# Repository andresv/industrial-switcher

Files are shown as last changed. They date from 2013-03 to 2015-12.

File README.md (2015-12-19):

## industrial-switcher

This board is meant for switching various 24V loads, like coils and relays.

## Requirements

[PlatformIO](http://platformio.org) is used for building.

```
pip install -U pip setuptools
pip install -U platformio
platformio platforms install timsp430
```

## Build and upload
```
platformio run
platformio run --target upload
```

## License

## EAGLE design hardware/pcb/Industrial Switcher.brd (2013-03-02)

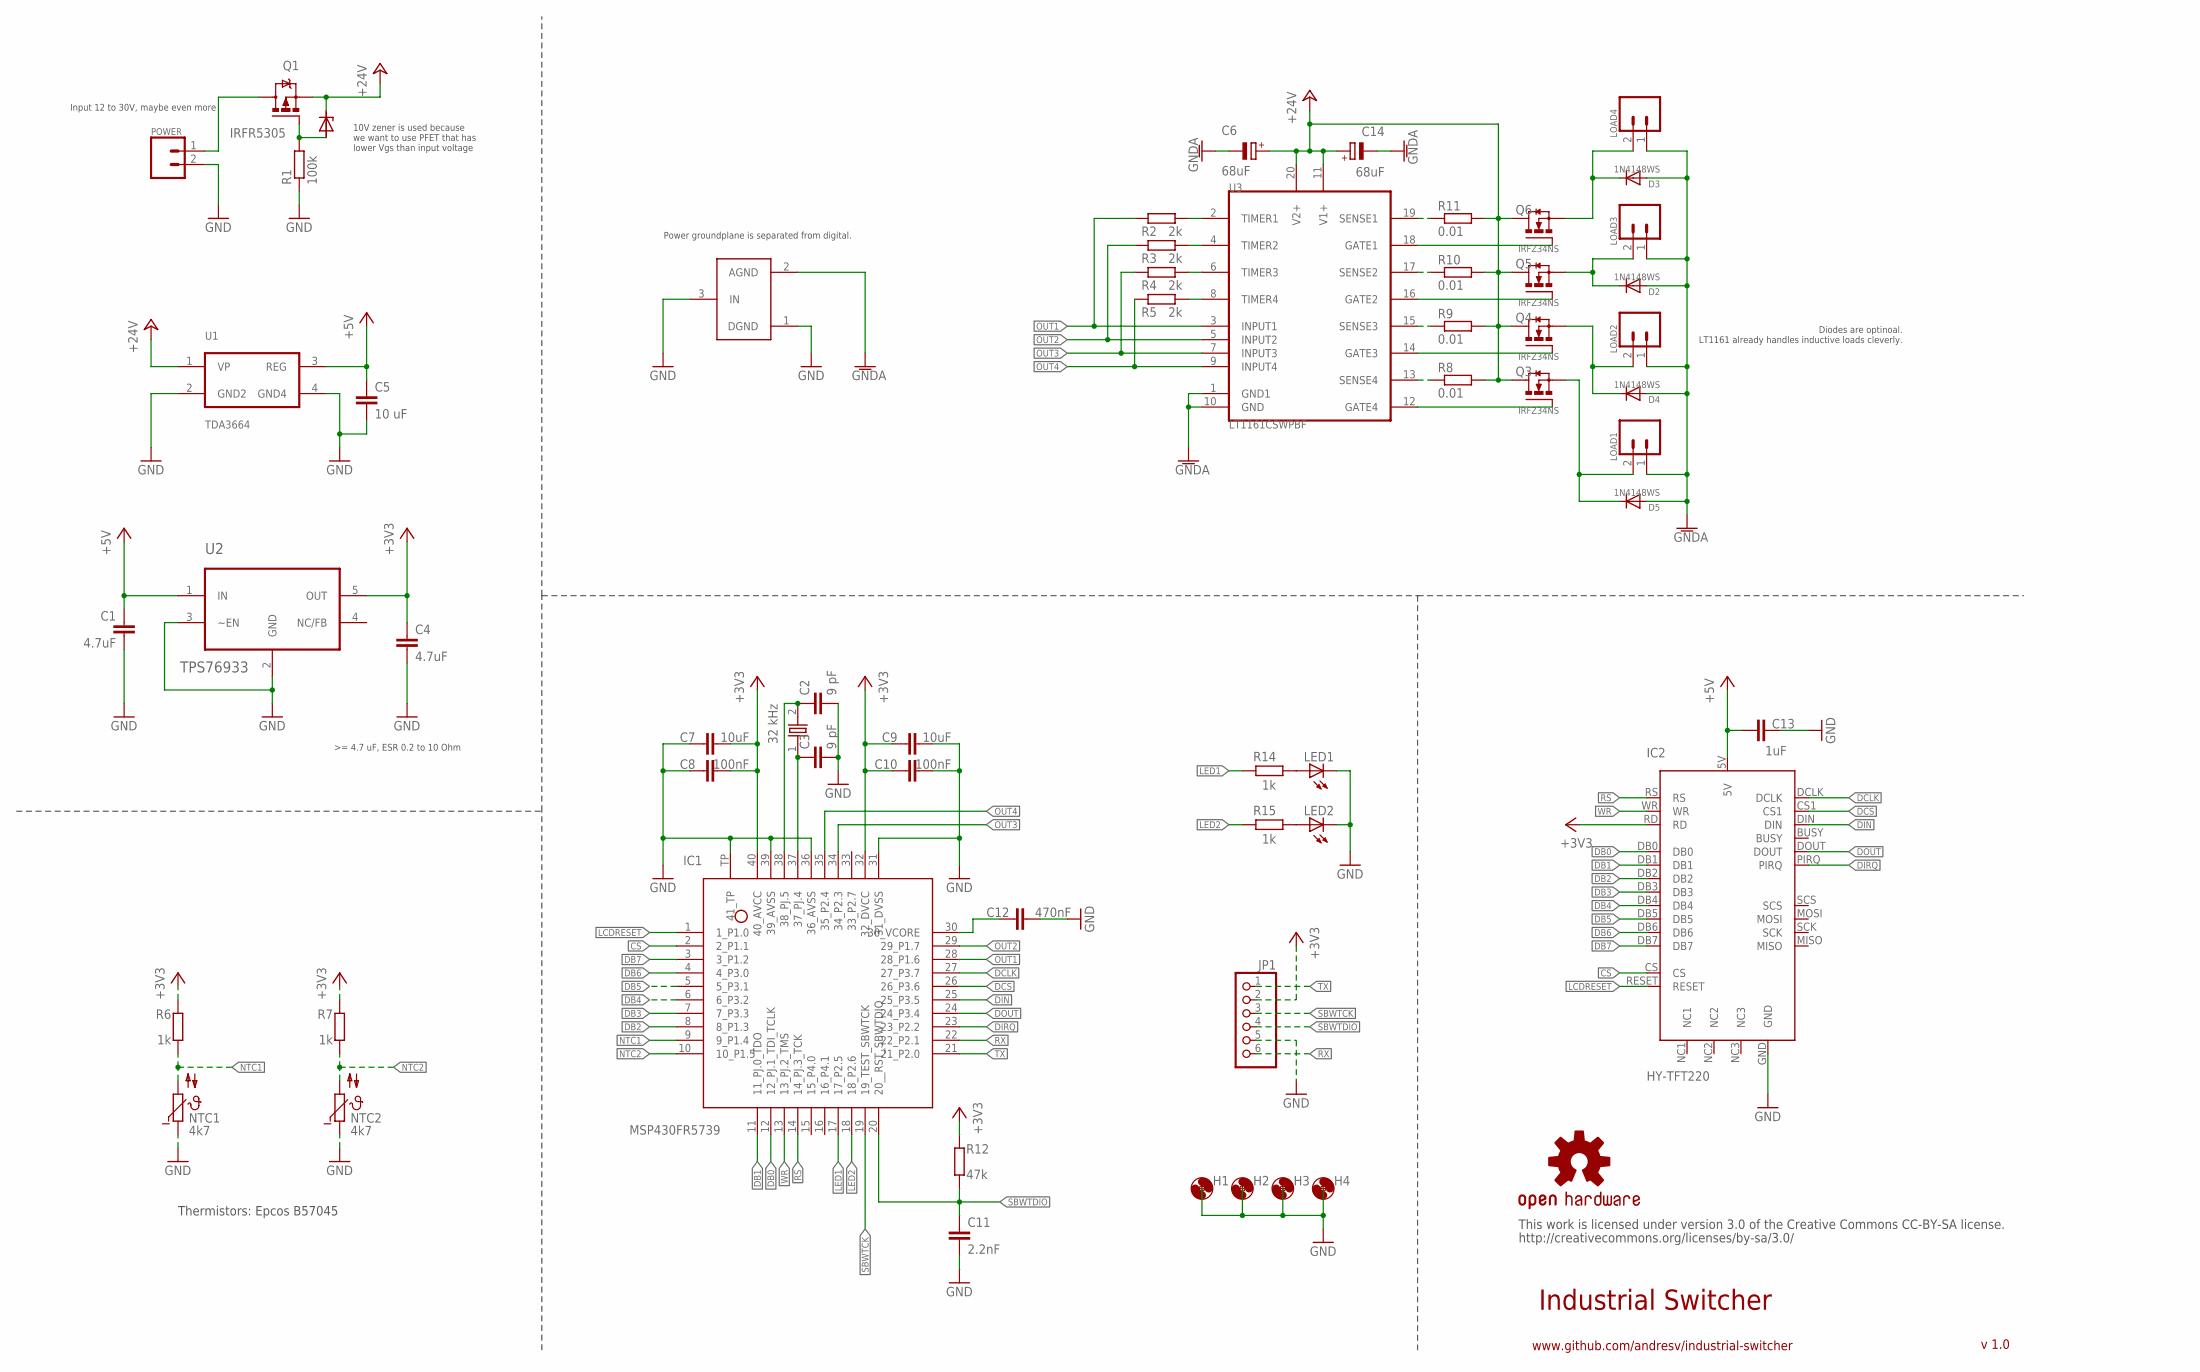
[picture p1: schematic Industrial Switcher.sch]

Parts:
C1: 4.7uF; C0805
C2, C3: 9 pF; C0402
C4: 4.7uF; C1206
C5: 10 uF; C1206
C6, C14: 68uF; PANASONIC_F
C7, C9: 10uF; C0603
C8, C10: 100nF; C0603
C11: 2.2nF; C0402
C12: 470nF; C0603
C13: 1uF; C0805
D1: 10V; SOD323-W
D2, D3, D4, D5: 1N4148WS; SOD323-W
H1, H2, H3, H4: MOUNT-HOLE3.0; 3,0
IC1: MSP430FR5739; RHA40
IC2: HY-TFT220; 2.2TFT
JP1: PINHD-1X6; 1X06
LED1, LED2: LEDCHIP-LED0603; CHIP-LED0603
LOAD1, LOAD2, LOAD3, LOAD4: M025MM; SCREWTERMINAL-5MM-2
LOGO2: OSHW-LOGOL; OSHW-LOGO-L
NTC1, NTC2: 4k7; N640
POWER: M025MM; SCREWTERMINAL-5MM-2
Q1: IRFR5305; D-PAK_TO252AA
Q2: 32 kHz; ABS07
Q3, Q4, Q5, Q6: IRFZ34NS; D2PACK
R1: 100k; R0603
R2, R3, R4, R5: 2k; R0603
R6, R7: 1k; R0603
R8, R9, R10, R11: 0.01; R0603
R12: 47k; R0402
R14, R15: 1k; R0402
U1: TDA3664; DRFRIEDPARTS/DOAAZ
U2: TPS76933; SOT95P280X145-5N
U3: LT1161CSWPBF; ANDRESV/B3JU7
U$1: GND_CONNECT

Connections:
+3V3: C4.1, C7.2, C8.2, C9.1, C10.1, IC1.32 (32_DVCC), IC1.40 (40_AVCC), IC2.RD, JP1.2, R6.2, R7.2, R12.2, U2.5 (OUT)
+5V: C1.1, C5.1, C13.2, IC2.5V, U1.3 (REG), U2.1 (IN)
+24V: C6.+, C14.+, D1.C, Q1.3 (S), Q3.2 (D), Q4.2 (D), Q5.2 (D), Q6.2 (D), R8.2, R9.2, R10.2, R11.2, U1.1 (VP), U3.11 (V1+), U3.20 (V2+)
CS: IC1.2 (2_P1.1), IC2.CS
DB0: IC1.12 (12_PJ.1_TDI_TCLK), IC2.DB0
DB1: IC1.11 (11_PJ.0_TDO), IC2.DB1
DB2: IC1.8 (8_P1.3), IC2.DB2
DB3: IC1.7 (7_P3.3), IC2.DB3
DB4: IC1.6 (6_P3.2), IC2.DB4
DB5: IC1.5 (5_P3.1), IC2.DB5
DB6: IC1.4 (4_P3.0), IC2.DB6
DB7: IC1.3 (3_P1.2), IC2.DB7
DCLK: IC1.27 (27_P3.7), IC2.DCLK
DCS: IC1.26 (26_P3.6), IC2.CS1
DIN: IC1.25 (25_P3.5), IC2.DIN
DIRQ: IC1.23 (23_P2.2), IC2.PIRQ
DOUT: IC1.24 (24_P3.4), IC2.DOUT
GND: C1.2, C2.2, C3.2, C4.2, C5.2, C7.1, C8.1, C9.2, C10.2, C11.2, C12.2, C13.1, IC1.31 (31_DVSS), IC1.36 (36_AVSS), IC1.39 (39_AVSS), IC1.TP (41_TP), IC2.GND, JP1.5, LED1.C, LED2.C, NTC1.1, NTC2.1, POWER.2, R1.1, U1.2 (GND2), U1.4 (GND4), U2.2 (GND), U2.3 (~EN), U$1.1 (DGND), U$1.3 (IN)
GNDA: C6.-, C14.-, D2.A, D3.A, D4.A, D5.A, LOAD1.1, LOAD2.1, LOAD3.1, LOAD4.1, U3.1 (GND1), U3.10 (GND), U$1.2 (AGND)
LCDRESET: IC1.1 (1_P1.0), IC2.RESET
LED1: IC1.17 (17_P2.5), R14.2
LED2: IC1.18 (18_P2.6), R15.2
unnamed: D1.A, Q1.1 (G), R1.2
unnamed: R5.2, U3.8 (TIMER4)
unnamed: R8.1, U3.13 (SENSE4)
unnamed: R9.1, U3.15 (SENSE3)
unnamed: D3.C, LOAD4.2, Q6.3 (S)
unnamed: R10.1, U3.17 (SENSE2)
unnamed: R4.2, U3.6 (TIMER3)
unnamed: D2.C, LOAD3.2, Q5.3 (S)
unnamed: R11.1, U3.19 (SENSE1)
unnamed: R3.2, U3.4 (TIMER2)
unnamed: D4.C, LOAD2.2, Q4.3 (S)
unnamed: POWER.1, Q1.4 (D)
unnamed: R2.2, U3.2 (TIMER1)
unnamed: D5.C, LOAD1.2, Q3.3 (S)
unnamed: Q6.1 (G), U3.18 (GATE1)
unnamed: C3.1, IC1.37 (37_PJ.4), Q2.1
unnamed: C2.1, IC1.38 (38_PJ.5), Q2.2
unnamed: C12.1, IC1.30 (30_VCORE)
unnamed: Q5.1 (G), U3.16 (GATE2)
unnamed: Q4.1 (G), U3.14 (GATE3)
unnamed: Q3.1 (G), U3.12 (GATE4)
unnamed: LED1.A, R14.1
unnamed: LED2.A, R15.1
NTC1: IC1.9 (9_P1.4), NTC1.2, R6.1
NTC2: IC1.10 (10_P1.5), NTC2.2, R7.1
OUT1: IC1.28 (28_P1.6), R2.1, U3.3 (INPUT1)
OUT2: IC1.29 (29_P1.7), R3.1, U3.5 (INPUT2)
OUT3: IC1.34 (34_P2.3), R4.1, U3.7 (INPUT3)
OUT4: IC1.35 (35_P2.4), R5.1, U3.9 (INPUT4)
RS: IC1.14 (14_PJ.3_TCK), IC2.RS
RX: IC1.22 (22_P2.1), JP1.6
SBWTCK: IC1.19 (19_TEST_SBWTCK), JP1.3
SBWTDIO: C11.1, IC1.20 (20__RST_SBWTDIO), JP1.4, R12.1
TX: IC1.21 (21_P2.0), JP1.1
WR: IC1.13 (13_PJ.2_TMS), IC2.WR

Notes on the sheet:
Industrial Switcher
www.github.com/andresv/industrial-switcher
v 1.0
This work is licensed under version 3.0 of the Creative Commons CC-BY-SA license.
http://creativecommons.org/licenses/by-sa/3.0/
Thermistors: Epcos B57045
10V zener is used because we want to use PFET that has lower Vgs than input voltage
Diodes are optinoal. LT1161 already handles inductive loads cleverly.
Input 12 to 30V, maybe even more
Power groundplane is separated from digital.

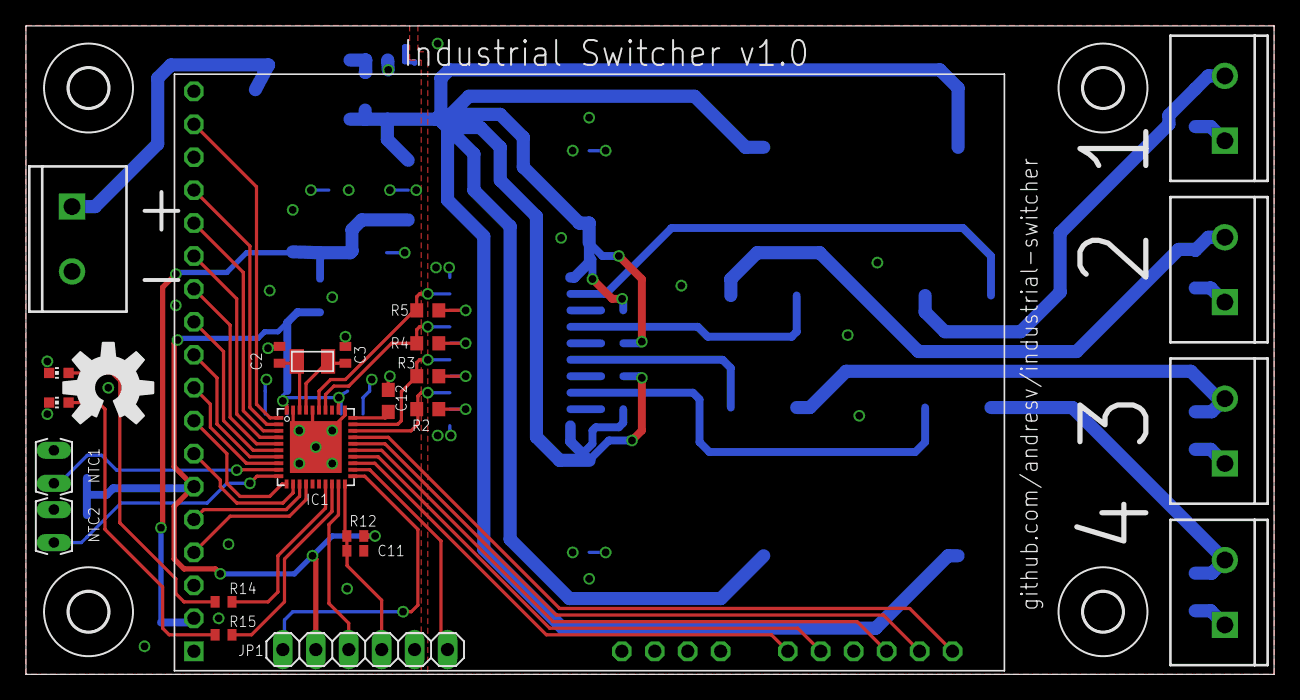
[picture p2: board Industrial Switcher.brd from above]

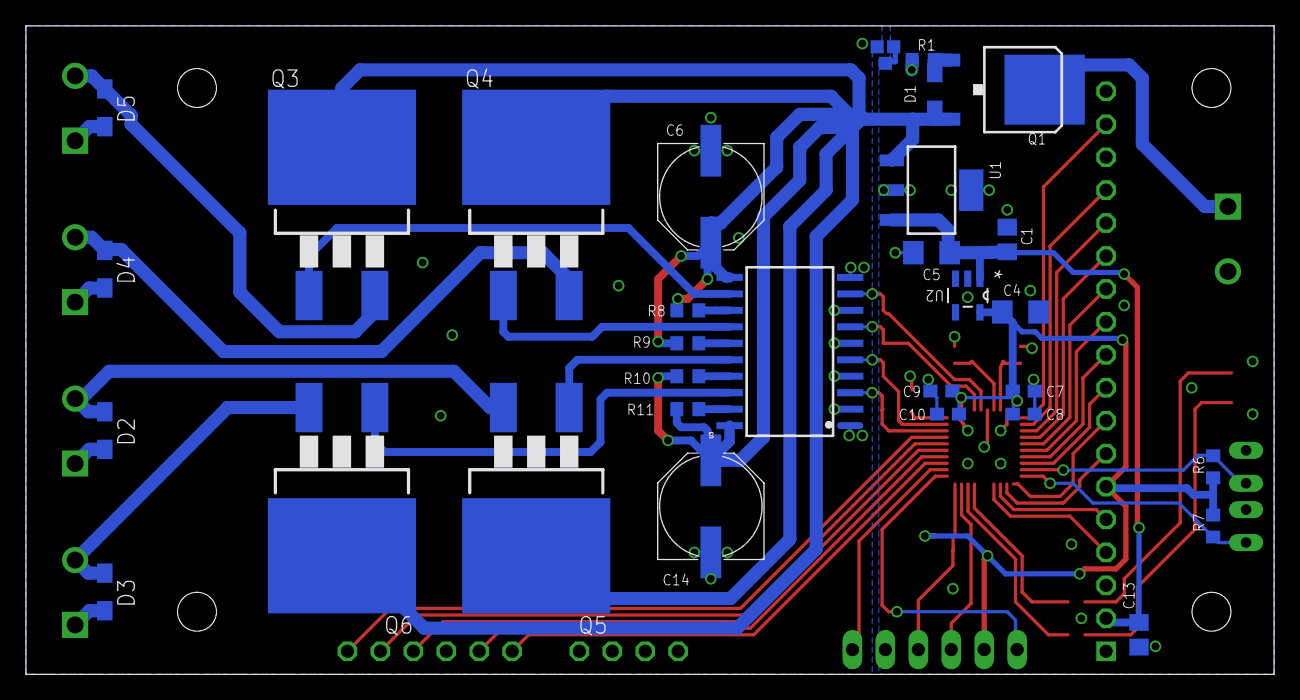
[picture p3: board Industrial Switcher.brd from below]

Board: 2 copper layers, 96.2 x 50.0 mm, 60 parts (31 on the bottom side), 57 nets.

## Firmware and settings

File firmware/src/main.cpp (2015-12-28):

/*
 * Copyright (c) 2013, Andres Vahter
 * All rights reserved.
 *
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
 * 3. Neither the name of the copyright holder nor the names of its
 *    contributors may be used to endorse or promote products derived
 *    from this software without specific prior written permission.
 *
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
 * Author: Andres Vahter (andres.vahter@gmail.com)
 */

#include <UTFT.h>
#include <UTouch.h>
#include "ntctable.h"
#include "garage.h"

#define G_GREEN_LED 3
#define G_RED_LED 4
// silk screen is wrong on v1.0 board, reverse order here
// 2.3 and 2.4 are not mapped in Energia, they are handled as raw GPIO
#define OUTPUT_3 12
#define OUTPUT_4 11

// temperature
#define NTC1_PIN A1
#define NTC2_PIN A0
#define SMOOTHING_BUFFER_SIZE 2
// It shows how many quick measurements are taken in the row for filtering
#define FILTER_BUFFER_SIZE 5
// It shows how many elements are discarded from the beginning
// and at the end of buffer
#define FILTER_OUT_COUNT 1
// for example we have following sorted measurements: 34, 56, 56, 58, 60
// 34 and 60 will be discarded if FILTER_OUT_COUNT is 1

// graphics
#define BOX_WIDTH 30
#define BOX_X_OFFSET 0
#define BOX_Y_OFFSET 28

#define CUR_TEMP1_X 55
#define CUR_TEMP1_Y 26
#define SET_TEMP1_X 135
#define SET_TEMP1_Y 26

#define CUR_TEMP2_X 55
#define CUR_TEMP2_Y 100
#define SET_TEMP2_X 135
#define SET_TEMP2_Y 100

// TFT pins
#define RS_PIN 28
#define WR_PIN 27
#define CS_PIN 14
#define RST_PIN 13

// Touch pins
#define T_CLK_PIN 10
#define T_TCS_PIN 9
#define T_DIN_PIN 8
#define T_OUT_PIN 7
#define T_IRQ_PIN 6

// ON/OFF regulator
#define UPPER_HYSTERESIS 3
#define LOWER_HYSTERESIS 1
#define CONTROL_OFF -127
#define HIGH_TEMP 60
#define HIGH_TEMP_TIME 60*60 // seconds

#define SAVED_STATE_FRAM_ADDRESS 0xFF1C
#define FRAM_MAGIC 0xCAFEBABE

extern uint8_t SmallFont[];
extern uint8_t SevenSegNumFont[];

UTFT TFT(HX8340B_8, RS_PIN, WR_PIN, CS_PIN, RST_PIN);
UTouch Touch(T_CLK_PIN, T_TCS_PIN, T_DIN_PIN, T_OUT_PIN, T_IRQ_PIN);

int8_t current_temp_1;
uint8_t temp_1_index = 0;
int8_t temp_1_choices[] = {CONTROL_OFF, HIGH_TEMP, 25};
int8_t current_temp_2;
uint8_t temp_2_index = 0;
int8_t temp_2_choices[] = {CONTROL_OFF, 25};

uint16_t filter_buf[FILTER_BUFFER_SIZE];
container_t filter_container;

short temp_1_buf[SMOOTHING_BUFFER_SIZE];
container_t temp_1_container;
short temp_2_buf[SMOOTHING_BUFFER_SIZE];
container_t temp_2_container;

uint32_t heater_last_timestamp = 0;
bool heater_is_on = false;
uint32_t milli_count = 0;
bool hysteresis_1_raising = true;
bool hysteresis_2_raising = false;

unsigned long *fram_params_ptr;
typedef struct {
    uint32_t magic;
    uint8_t temp_1_index;
    uint8_t temp_2_index;
    uint32_t milli_count;
}fram_params_t;

fram_params_t framparams;

void draw_main_screen();
void draw_set_temp_1();
void draw_set_temp_2();
void clear_number(int x1, int y1);
void switch_out_1(bool onoff);
void switch_out_2(bool onoff);
void switch_out_3(bool onoff);
void switch_out_4(bool onoff);
void save_parameters_to_fram();
void read_parameters_from_fram();
int convert_raw_to_celsius(int rawtemp);

void init_containers() {
    short temp;
    uint8_t i;

    filter_container.index = 0;
    filter_container.len = FILTER_BUFFER_SIZE;
    filter_container.buffer = (short*)filter_buf;

    temp_1_container.index = 0;
    temp_1_container.len = SMOOTHING_BUFFER_SIZE;
    temp_1_container.buffer = temp_1_buf;

    temp_2_container.index = 0;
    temp_2_container.len = SMOOTHING_BUFFER_SIZE;
    temp_2_container.buffer = temp_2_buf;

    // fill in averaging buffers with initial temperature values
    temp = convert_raw_to_celsius(analogRead(NTC2_PIN)); // temp_1 is NTC2
    for (i=0; i<SMOOTHING_BUFFER_SIZE; i++) {
        temp_1_container.buffer[i] = temp;
    }

    temp = convert_raw_to_celsius(analogRead(NTC1_PIN)); // temp_2 is NTC1
    for (i=0; i<SMOOTHING_BUFFER_SIZE; i++) {
        temp_2_container.buffer[i] = temp;
    }
}

void setup() {
    pinMode(G_GREEN_LED, OUTPUT);
    pinMode(G_RED_LED, OUTPUT);
    P2DIR |= (1<<4); // OUTPUT_1
    P2DIR |= (1<<3); // OUTPUT_2
    pinMode(OUTPUT_3, OUTPUT);
    pinMode(OUTPUT_4, OUTPUT);
    pinMode(NTC1_PIN, INPUT);
    pinMode(NTC2_PIN, INPUT);

    digitalWrite(G_RED_LED, HIGH);

    TFT.InitLCD();
    Touch.InitTouch(LANDSCAPE);
    Touch.setPrecision(PREC_MEDIUM);

    read_parameters_from_fram();

    init_containers();

    draw_main_screen();
}

void draw_main_screen() {
    TFT.clrScr();

    // draw output indicators
    TFT.setColor(VGA_WHITE);
    TFT.drawRect(BOX_X_OFFSET, BOX_Y_OFFSET, BOX_WIDTH, BOX_WIDTH + BOX_Y_OFFSET);
    TFT.drawRect(BOX_X_OFFSET, BOX_Y_OFFSET+1*BOX_WIDTH, BOX_WIDTH, 2*BOX_WIDTH + BOX_Y_OFFSET);
    TFT.drawRect(BOX_X_OFFSET, BOX_Y_OFFSET+2*BOX_WIDTH, BOX_WIDTH, 3*BOX_WIDTH + BOX_Y_OFFSET);
    TFT.drawRect(BOX_X_OFFSET, BOX_Y_OFFSET+3*BOX_WIDTH, BOX_WIDTH, 4*BOX_WIDTH + BOX_Y_OFFSET);

    // color chamber
    TFT.setFont(SmallFont);
    TFT.print("in", 80, 10);
    draw_set_temp_1();

    // garage
    TFT.setFont(SmallFont);
    TFT.setColor(VGA_WHITE);
    TFT.print("out", 75, 150);
    draw_set_temp_2();
}

void draw_set_temp_1() {
    if (temp_1_index >= sizeof(temp_1_choices)/sizeof(int8_t)) {
        temp_1_index = 0;
    }
    if (temp_1_choices[temp_1_index] == CONTROL_OFF) {
        clear_number(SET_TEMP1_X, SET_TEMP1_Y);
    }
    else {
        // HIGH_TEMP degrees should be active only for 1 h
        if (temp_1_choices[temp_1_index] == HIGH_TEMP) {
            heater_last_timestamp = millis();
            heater_is_on = true;
        }
        else {
            heater_is_on = false;
            milli_count = 0;
            TFT.setColor(VGA_WHITE);
            TFT.setFont(SmallFont);
            TFT.print("      ", 149, 10);
        }

        TFT.setColor(VGA_RED);
        TFT.setFont(SevenSegNumFont);
        TFT.printNumI(temp_1_choices[temp_1_index], SET_TEMP1_X, SET_TEMP1_Y, 2, '0');
    }
}

void draw_set_temp_2() {
    if (temp_2_index >= sizeof(temp_2_choices)/sizeof(int8_t)) {
        temp_2_index = 0;
    }
    if (temp_2_choices[temp_2_index] == CONTROL_OFF) {
        clear_number(SET_TEMP2_X, SET_TEMP2_Y);
    }
    else {
        TFT.setColor(VGA_RED);
        TFT.setFont(SevenSegNumFont);
        TFT.printNumI(temp_2_choices[temp_2_index], SET_TEMP2_X, SET_TEMP2_Y, 2, '0');
    }
}

void clear_number(int x1, int y1) {
    TFT.setColor(VGA_BLACK);
    TFT.fillRect(x1, y1, x1 + 60, y1 + 60);
}

void switch_out_4(bool onoff) {
    if (onoff) {
        digitalWrite(OUTPUT_4, HIGH);
        TFT.setColor(VGA_GREEN);
    }
    else {
        digitalWrite(OUTPUT_4, LOW);
        TFT.setColor(VGA_BLACK);
    }
    TFT.fillRect(BOX_X_OFFSET+1, BOX_Y_OFFSET+1, BOX_WIDTH-1, BOX_WIDTH + BOX_Y_OFFSET-1);
}

void switch_out_3(bool onoff) {
    if (onoff) {
        digitalWrite(OUTPUT_3, HIGH);
        TFT.setColor(VGA_GREEN);
    }
    else {
        digitalWrite(OUTPUT_3, LOW);
        TFT.setColor(VGA_BLACK);
    }
    TFT.fillRect(BOX_X_OFFSET+1, BOX_Y_OFFSET+1*BOX_WIDTH+1, BOX_WIDTH-1, 2*BOX_WIDTH + BOX_Y_OFFSET-1);
}

void switch_out_2(bool onoff) {
    if (onoff) {
        P2OUT |= (1<<3);
        TFT.setColor(VGA_GREEN);
    }
    else {
        P2OUT &= ~(1<<3);
        TFT.setColor(VGA_BLACK);
    }
    TFT.fillRect(BOX_X_OFFSET+1, BOX_Y_OFFSET+2*BOX_WIDTH+1, BOX_WIDTH-1, 3*BOX_WIDTH + BOX_Y_OFFSET-1);
}

void switch_out_1(bool onoff) {
    if (onoff) {
        P2OUT |= (1<<4);
        TFT.setColor(VGA_GREEN);
    }
    else {
        P2OUT &= ~(1<<4);
        TFT.setColor(VGA_BLACK);
    }
    TFT.fillRect(BOX_X_OFFSET+1, BOX_Y_OFFSET+3*BOX_WIDTH+1, BOX_WIDTH-1, 4*BOX_WIDTH + BOX_Y_OFFSET-1);
}

int convert_raw_to_celsius(int rawtemp) {
    int current_celsius = 0;
    int i = 0;

    for (i=1; i < NUMTEMPS; i++) {
        if (temptable[i][0] > rawtemp) {
            int realtemp = temptable[i-1][1] + (rawtemp - temptable[i-1][0]) * (temptable[i][1] - temptable[i-1][1]) / (temptable[i][0] - temptable[i-1][0]);
            if (realtemp > 255) {
                realtemp = 255;
            }

            current_celsius = realtemp;
            break;
        }
    }

    // Overflow: Clamp to -50 degrees celsius
    if (i == NUMTEMPS) {
        current_celsius = -50;
    }

    return current_celsius;
}

void container_append(container_t* container, short element) {
    container->buffer[container->index] = element;
    container->index++;
    if (container->index == container->len) {
        container->index = 0;
    }
}

short container_average(container_t* container) {
    short sum = 0;
    uint8_t i;

    for (i = 0; i < container->len; i++) {
        sum += container->buffer[i];
    }
    return (sum / container->len);
}

void container_sort(container_t* container) {
    // bubble sort
    uint8_t i, j;
    short temp;

    for (i=0; i<container->len ; i++) {
       for (j=0; j<(container->len-1)-i; j++) {
         if (container->buffer[j] < container->buffer[j+1] ) {
            temp = container->buffer[j];
            container->buffer[j] = container->buffer[j+1];
            container->buffer[j+1] = temp;
         }
       }
    }
}

int read_temp(int adc_nr) {
    uint8_t i = 0;
    uint16_t sum = 0;

    // take couple of readings as fast as possible
    for (i=0; i<FILTER_BUFFER_SIZE; i++) {
        container_append(&filter_container, analogRead(adc_nr));
    }

    // filter out smallest and biggest readings (might be outliers)
    container_sort(&filter_container);
    for (i=FILTER_OUT_COUNT; i<FILTER_BUFFER_SIZE - FILTER_OUT_COUNT; i++) {
        sum += filter_container.buffer[i];
    }

    return convert_raw_to_celsius(sum/(FILTER_BUFFER_SIZE - 2*FILTER_OUT_COUNT));
}

void read_temp_sensors() {
    container_append(&temp_1_container, read_temp(NTC2_PIN));
    current_temp_1 = container_average(&temp_1_container);

    container_append(&temp_2_container, read_temp(NTC1_PIN));
    current_temp_2 = container_average(&temp_2_container);

    // only 2 digits can be shown and we do not support negative numbers
    if (current_temp_1 > 99) {
        current_temp_1 = 99;
    }
    else if (current_temp_1 < 0) {
        current_temp_1 = 0;
    }
    if (current_temp_2 > 99) {
        current_temp_2 = 99;
    }
    else if (current_temp_2 < 0) {
        current_temp_2 = 0;
    }

    TFT.setFont(SevenSegNumFont);
    TFT.setColor(VGA_WHITE);
    TFT.printNumI(current_temp_1, CUR_TEMP1_X, CUR_TEMP1_Y, 2, '0');
    TFT.printNumI(current_temp_2, CUR_TEMP2_X, CUR_TEMP2_Y, 2, '0');
}

void save_parameters_to_fram() {
    framparams.magic = FRAM_MAGIC;
    framparams.temp_1_index = temp_1_index;
    framparams.temp_2_index = temp_2_index;
    framparams.milli_count = milli_count;
    fram_params_ptr = (unsigned long *)SAVED_STATE_FRAM_ADDRESS;
    memcpy((void*)fram_params_ptr, &framparams, sizeof(fram_params_t));
}

void read_parameters_from_fram() {
    fram_params_t* parameters;
    fram_params_ptr = (unsigned long *)SAVED_STATE_FRAM_ADDRESS;
    parameters = (fram_params_t*)fram_params_ptr;
    if (parameters->magic == FRAM_MAGIC) {
        temp_1_index = parameters->temp_1_index;
        temp_2_index = parameters->temp_2_index;
        milli_count = parameters->milli_count;
    }
}

uint32_t tx=0;
uint32_t ty=0;
bool led_on = true;
void loop() {
    // status blink
    if (led_on) {
        digitalWrite(G_GREEN_LED, HIGH);
        led_on = false;
    }
    else {
        digitalWrite(G_GREEN_LED, LOW);
        led_on = true;
    }

    if (Touch.dataAvailable()) {
        delay(100);

        Touch.read();
        tx = Touch.getX();
        ty = Touch.getY();

        // sometimes x is reported as 219
        // and y is reported as 0, actually they are not
        // filter those touches out
        if (tx != 219 && ty != 0) {
            // check if lower right sector was touched
            if (ty > 90) {
                temp_2_index++;
                draw_set_temp_2();
            }
            // check if upper right sector was touched
            else if (ty < 80) {
                temp_1_index++;
                draw_set_temp_1();
            }
        }
    }

    read_temp_sensors();

    // HIGH_TEMP degrees should be active only for 1 h
    if (heater_is_on) {
        uint32_t timestamp = millis();
        milli_count += (timestamp - heater_last_timestamp);
        heater_last_timestamp = timestamp;

        if (milli_count/1000 < HIGH_TEMP_TIME) {
            TFT.setColor(VGA_WHITE);
            TFT.setFont(SmallFont);
            TFT.printNumI((HIGH_TEMP_TIME - milli_count/1000) / 60, 149, 12, 2, '0');
            TFT.print(":", 164, 11);
            TFT.printNumI((HIGH_TEMP_TIME - milli_count/1000) % 60, 172, 12, 2, '0');
        }
        else {
            TFT.setColor(VGA_WHITE);
            TFT.setFont(SmallFont);
            TFT.print("      ", 149, 10);
            heater_is_on = false;
            milli_count = 0;
            temp_1_index++;
            draw_set_temp_1();
        }
    }

    //---------------------------------------------------------------
    // 1 ON-OFF regulator
    //---------------------------------------------------------------
    // upper point
    if (hysteresis_1_raising && (current_temp_1 >= (temp_1_choices[temp_1_index] + UPPER_HYSTERESIS))) {
        hysteresis_1_raising = false;
    }
    // lower point
    else if (!hysteresis_1_raising && (current_temp_1 <= (temp_1_choices[temp_1_index] - LOWER_HYSTERESIS))) {
        hysteresis_1_raising = true;
    }
    // raising
    if (hysteresis_1_raising) {
        switch_out_4(HIGH);
    }
    // falling
    else {
        switch_out_4(LOW);
    }

    //---------------------------------------------------------------
    // 2 ON-OFF regulator
    //---------------------------------------------------------------
    // upper point
    if (hysteresis_2_raising && (current_temp_2 >= (temp_2_choices[temp_2_index] + UPPER_HYSTERESIS))) {
        hysteresis_2_raising = false;
    }
    // lower point
    else if (!hysteresis_2_raising && (current_temp_2 <= (temp_2_choices[temp_2_index] - LOWER_HYSTERESIS))) {
        hysteresis_2_raising = true;
    }
    // raising
    if (hysteresis_2_raising) {
        switch_out_1(HIGH);
    }
    // falling
    else {
        switch_out_1(LOW);
    }

    save_parameters_to_fram();
}

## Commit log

2013-02-24 Added initial schematic
    [Industrial Switcher.brd, Industrial Switcher.sch]
2013-02-24 Routing almost finished.
    [Industrial Switcher.brd, Industrial Switcher.sch]
2013-02-25 Rearranged pins for better layout.
    [Industrial Switcher.brd, Industrial Switcher.sch]
2013-02-26 Added LEDs and did some more routing.
    [Industrial Switcher.brd, Industrial Switcher.sch]
2013-02-27 PCB seems to be now ready
    [Industrial Switcher.brd]
2013-02-28 Added optional flyback diodes to loads.
    [Industrial Switcher.brd, Industrial Switcher.sch]
2013-02-28 Separated digital and power groundplane.
    [Industrial Switcher.brd, Industrial Switcher.sch]
2013-03-02 Replaced OSHW logo.
    [Industrial Switcher.brd, Industrial Switcher.sch]
2013-04-07 Added Energia support to UTFT library.
    Currently only 8 bit HX8340B_8 display is tested on custom MSP430FR5739 board.
2013-04-07 Added trivial TFT use case to garage.ino
2013-04-09 Added 2.2" calibration constants
2013-04-10 Added on-off regulator with hysteresis.
2013-04-11 Fixed number padding, added status LED
2013-04-12 Added current state saving to FRAM
2013-11-29 add temperature input smoothing and discard strange values
2013-12-24 add better temperature filtering and outliers discarding
2013-12-24 remove duplications from switch functions
2015-12-28 try to set F_CPU to 8 MHz and turn on red LED on boot

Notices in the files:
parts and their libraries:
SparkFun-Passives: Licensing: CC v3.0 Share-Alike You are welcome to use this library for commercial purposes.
